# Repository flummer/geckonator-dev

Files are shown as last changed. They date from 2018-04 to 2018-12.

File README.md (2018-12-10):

# Geckonator Dev Edition

This is a follow-up version og the [original Geckonator hardware][geckonator-hw] and is, similarly to the original, designed to help in early design work with the Silabs Happy Gecko family of USB microsontrollers.

This board, compared to the original, has two buttons (one to enter bootloader mode and one for power), a larger chip with more pins, all broken out, 3 LED's instead of 2, and a large prototyping area, where other stuff can be soldered on to for a semi permanent setup.

[geckonator-hw]: https://github.com/flummer/geckonator-hw

## Firmware

This board is designed for the development of the [Geckoboot bootloader][geckoboot], and for developing applications for this, the [Geckonator][geckonator] repository can be used as a base

[geckoboot]: https://github.com/flummer/geckoboot
[geckonator]: https://github.com/flummer/geckonator

## Hardware

This design is using the [Seeed OPL for KiCad library][seeed-opl] for all components, except for the EMF32 microcontroller. They are all standard components and can easily be replaced with parts sourced from other places.

[seeed-opl]: https://github.com/Seeed-Studio/OPL_Kicad_Library

## License

The contents of this repository is released under the following licence:

 * the "Creative Commons Attribution-ShareAlike 4.0 International License"
   (CC BY-SA 4.0) full text of this license is included in the LICENSE file
   and a copy can also be found at
   http://creativecommons.org/licenses/by-sa/4.0/

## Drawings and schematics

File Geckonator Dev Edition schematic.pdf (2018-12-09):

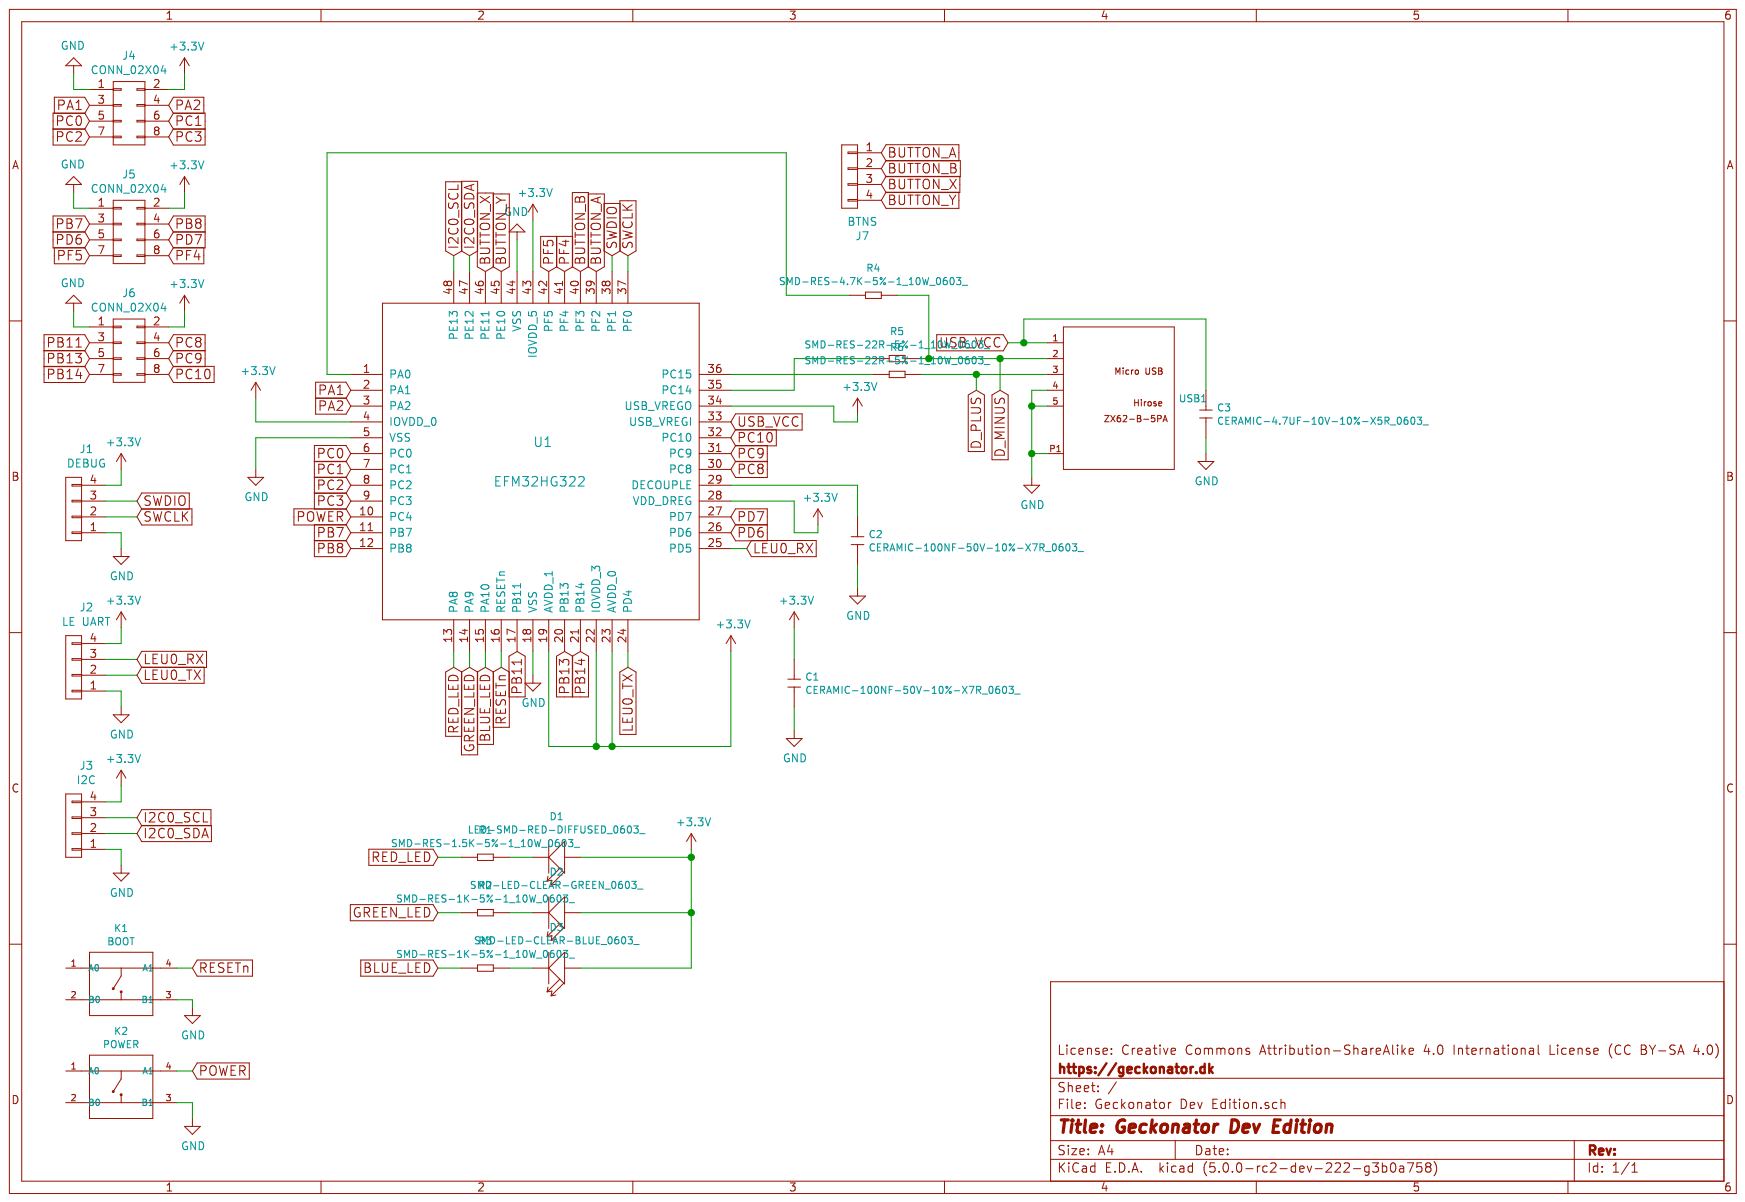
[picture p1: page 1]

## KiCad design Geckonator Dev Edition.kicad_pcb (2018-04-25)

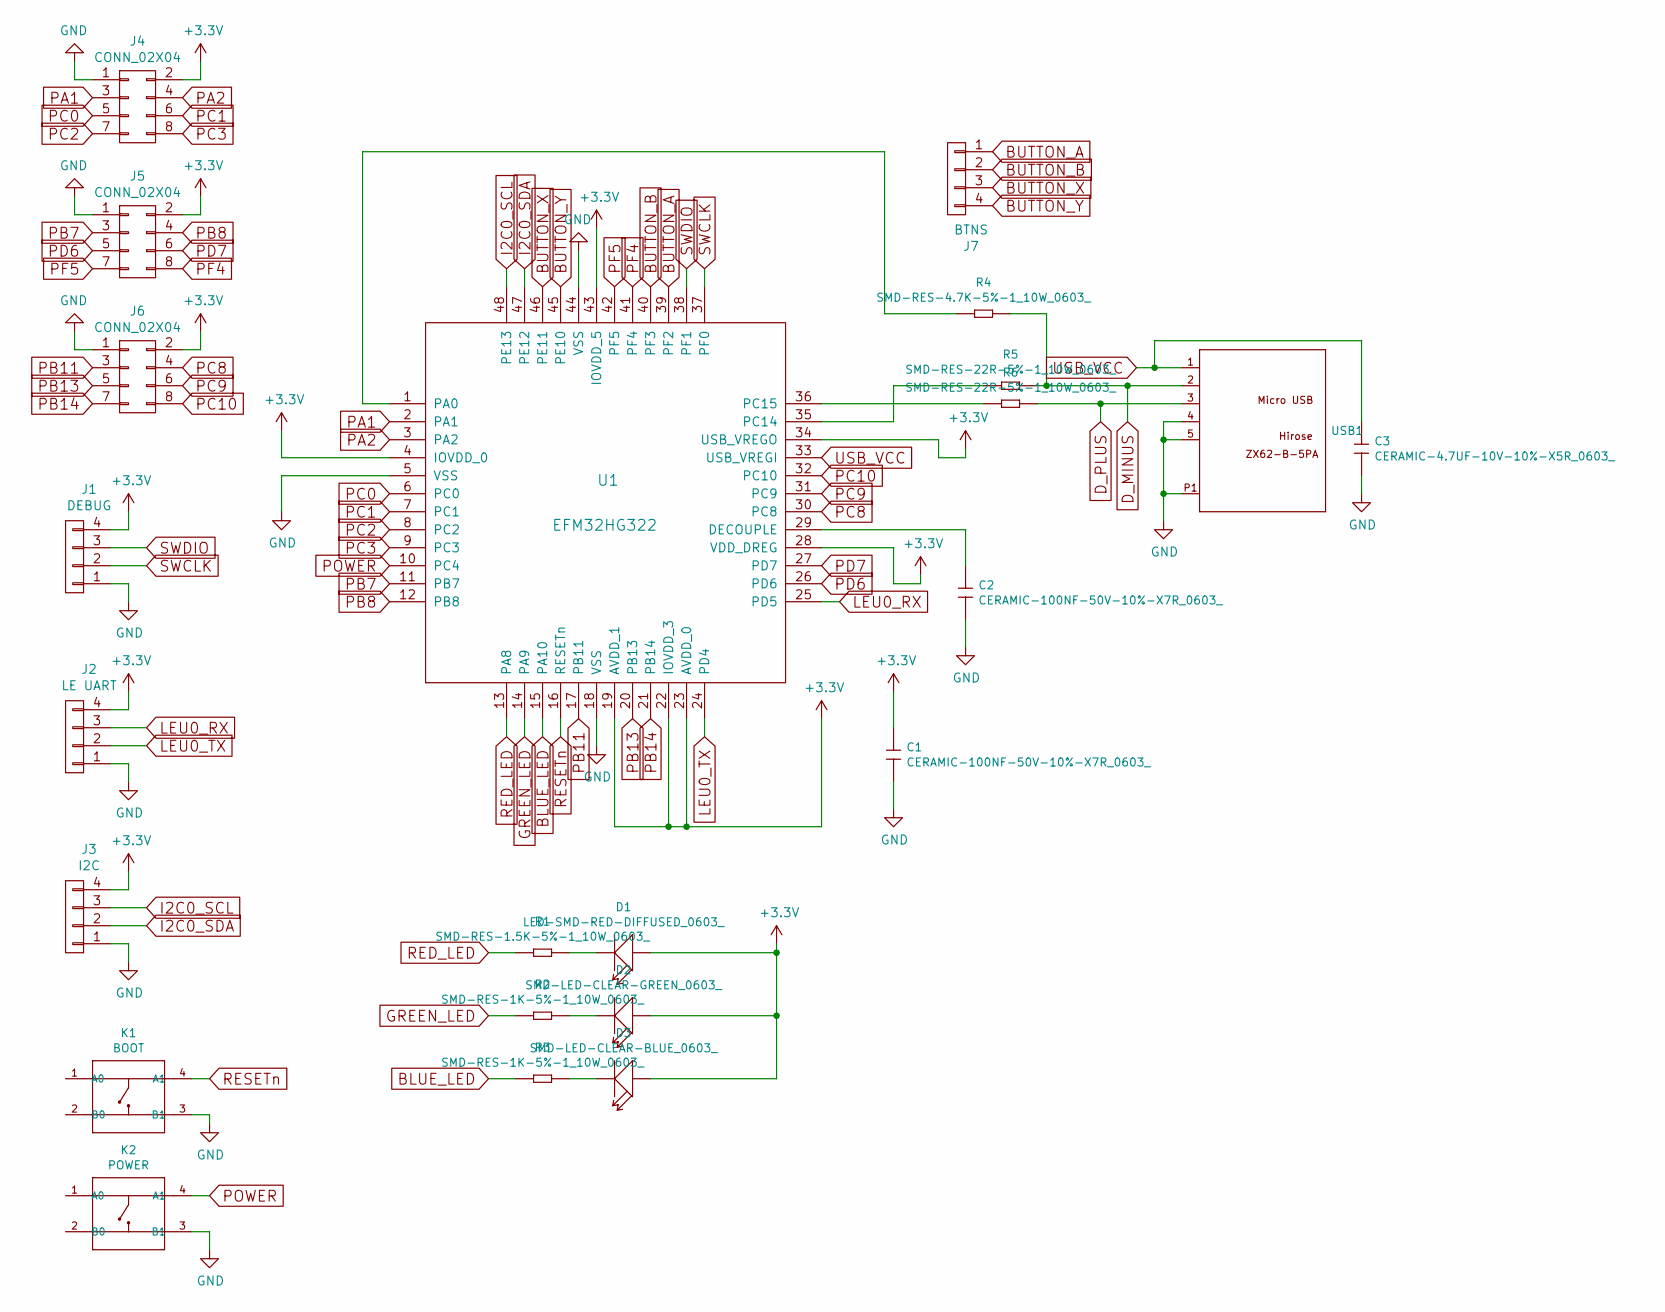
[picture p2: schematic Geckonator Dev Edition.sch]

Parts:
C1, C2: CERAMIC-100NF-50V-10%-X7R_0603_; C0603; MPN CC0603KRX7R9BB104
C3: CERAMIC-4.7UF-10V-10%-X5R_0603_; C0603; MPN CC0603KRX5R6BB475
D1: LED-SMD-RED-DIFFUSED_0603_; LED-0603; MPN 19-217-R6C-AL1M2VY-3T
D2: SMD-LED-CLEAR-GREEN_0603_; LED-0603; MPN 19-217-G7C-AN1P2-3T
D3: SMD-LED-CLEAR-BLUE_0603_; LED-0603; MPN 19-217-BHC-ZL1M2RY-3T
J1: DEBUG; Pin_Header_Straight_1x04_Pitch2.54mm
J2: LE UART; Pin_Header_Straight_1x04_Pitch2.54mm
J3: I2C; Pin_Header_Straight_1x04_Pitch2.54mm
J4, J5, J6: CONN_02X04; Pin_Header_Straight_2x04_Pitch2.54mm
J7: BTNS; Pin_Header_Straight_1x04_Pitch2.54mm
K1: BOOT; SW4-SMD-6.0X6.0X5.0MM; MPN DTSM-62K-S-V-T_R_SN431_
K2: POWER; SW4-SMD-6.0X6.0X5.0MM; MPN DTSM-62K-S-V-T_R_SN431_
R1: SMD-RES-1.5K-5%-1_10W_0603_; R0603; MPN RC0603JR-071K5L
R2, R3: SMD-RES-1K-5%-1_10W_0603_; R0603; MPN RC0603JR-071KL
R4: SMD-RES-4.7K-5%-1_10W_0603_; R0603; MPN RC0603JR-074K7L
R5, R6: SMD-RES-22R-5%-1_10W_0603_; R0603; MPN RC0603JR-0722RL
U1: EFM32HG322; TQFP-48_7x7mm_Pitch0.5mm
USB1: MICRO-USB-SMD_ZX62-B-5PA_; MICRO-USB5+6P-SMD-0.65-AB; MPN ZX62-B-5PA

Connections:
+3V3: C1.1, D1.+, D2.+, D3.+, J1.4, J2.4, J3.4, J4.2, J5.2, J6.2, U1.4 (IOVDD_0), U1.19 (AVDD_1), U1.22 (IOVDD_3), U1.23 (AVDD_0), U1.28 (VDD_DREG), U1.34 (USB_VREGO), U1.43 (IOVDD_5)
BLUE_LED: R3.1, U1.15 (PA10)
BUTTON_A: J7.1, U1.39 (PF2)
BUTTON_B: J7.2, U1.40 (PF3)
BUTTON_X: J7.3, U1.46 (PE11)
BUTTON_Y: J7.4, U1.45 (PE10)
D_MINUS: R4.2, R5.2, USB1.2 (D-)
D_PLUS: R6.2, USB1.3 (D+)
GND: C1.2, C2.2, C3.2, J1.1, J2.1, J3.1, J4.1, J5.1, J6.1, K1.3 (B1), K2.3 (B1), U1.5 (VSS), U1.18 (VSS), U1.44 (VSS), USB1.4 (ID), USB1.5 (GND), USB1.P1 (SHIELD), USB1.P2 (SHIELD), USB1.P3 (SHIELD), USB1.P4 (SHIELD), USB1.P5 (SHIELD), USB1.P6 (SHIELD)
GREEN_LED: R2.1, U1.14 (PA9)
I2C0_SCL: J3.3, U1.48 (PE13)
I2C0_SDA: J3.2, U1.47 (PE12)
LEU0_RX: J2.3, U1.25 (PD5)
LEU0_TX: J2.2, U1.24 (PD4)
unnamed: C2.1, U1.29 (DECOUPLE)
unnamed: D1.-, R1.2
unnamed: D2.-, R2.2
unnamed: D3.-, R3.2
unnamed: R4.1, U1.1 (PA0)
unnamed: R5.1, U1.35 (PC14)
unnamed: R6.1, U1.36 (PC15)
PA1: J4.3, U1.2 (PA1)
PA2: J4.4, U1.3 (PA2)
PB7: J5.3, U1.11 (PB7)
PB8: J5.4, U1.12 (PB8)
PB11: J6.3, U1.17 (PB11)
PB13: J6.5, U1.20 (PB13)
PB14: J6.7, U1.21 (PB14)
PC0: J4.5, U1.6 (PC0)
PC1: J4.6, U1.7 (PC1)
PC2: J4.7, U1.8 (PC2)
PC3: J4.8, U1.9 (PC3)
PC8: J6.4, U1.30 (PC8)
PC9: J6.6, U1.31 (PC9)
PC10: J6.8, U1.32 (PC10)
PD6: J5.5, U1.26 (PD6)
PD7: J5.6, U1.27 (PD7)
PF4: J5.8, U1.41 (PF4)
PF5: J5.7, U1.42 (PF5)
POWER: K2.4 (A1), U1.10 (PC4)
RED_LED: R1.1, U1.13 (PA8)
RESETn: K1.4 (A1), U1.16 (RESETn)
SWCLK: J1.2, U1.37 (PF0)
SWDIO: J1.3, U1.38 (PF1)
USB_VCC: C3.1, U1.33 (USB_VREGI), USB1.1 (VBUS)

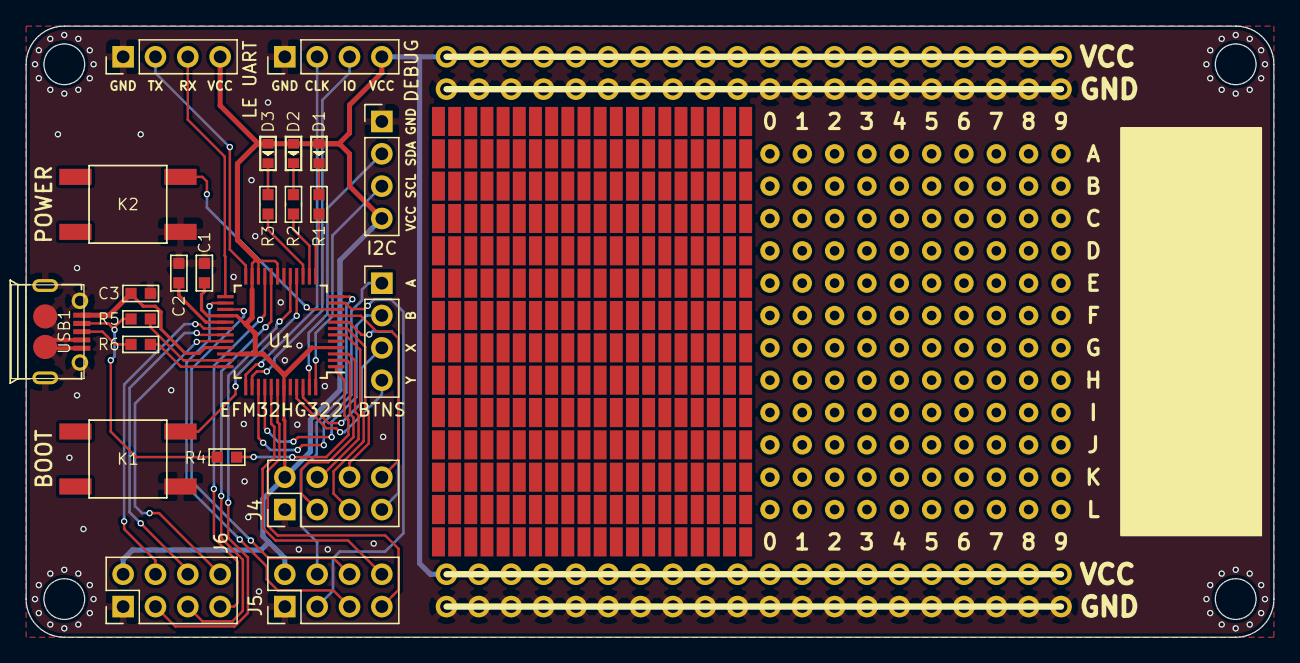
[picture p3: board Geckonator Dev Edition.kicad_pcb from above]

Board: 2 copper layers, 98.0 x 48.0 mm, 23 parts (0 on the bottom side), 45 nets.

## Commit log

2018-03-18 Initial version
    Only schematics
    [Geckonator Dev Edition.kicad_pcb, Geckonator Dev Edition.sch]
2018-04-25 Added silkscreen, etc.
    This corresponds to the first version produced
    [Geckonator Dev Edition.kicad_pcb, Geckonator Dev Edition.sch]
2018-04-25 Added gerber files
    Also added .gitignore
    [Geckonator Dev Edition-B.Cu.gbl, Geckonator Dev Edition-B.Mask.gbs, Geckonator Dev Edition-B.SilkS.gbo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]
2018-12-09 Added PDF schematic, licensing info and efm32 lib
    [Geckonator Dev Edition.sch]
